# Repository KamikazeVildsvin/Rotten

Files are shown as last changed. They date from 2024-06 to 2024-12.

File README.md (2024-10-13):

# Rotten - DIY Pro Co RAT Clone
This repository contains the KiCad files for a DIY clone of the classic Pro Co RAT distortion effect pedal.
The schematic is an implementation of the one found on [ElectroSmash](https://www.electrosmash.com/proco-rat), so a big shout-out to them.
The article on [ElectroSmash](https://www.electrosmash.com/proco-rat) has a great description of the functionality of the circuit.

## Interactive BOM
An [interactive HTML BOM](https://html-preview.github.io/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) can be found in the `PCB/Rotten/bom` directory.
This can be used as a tool to easier populate the PCB.

## Images
### Schematic
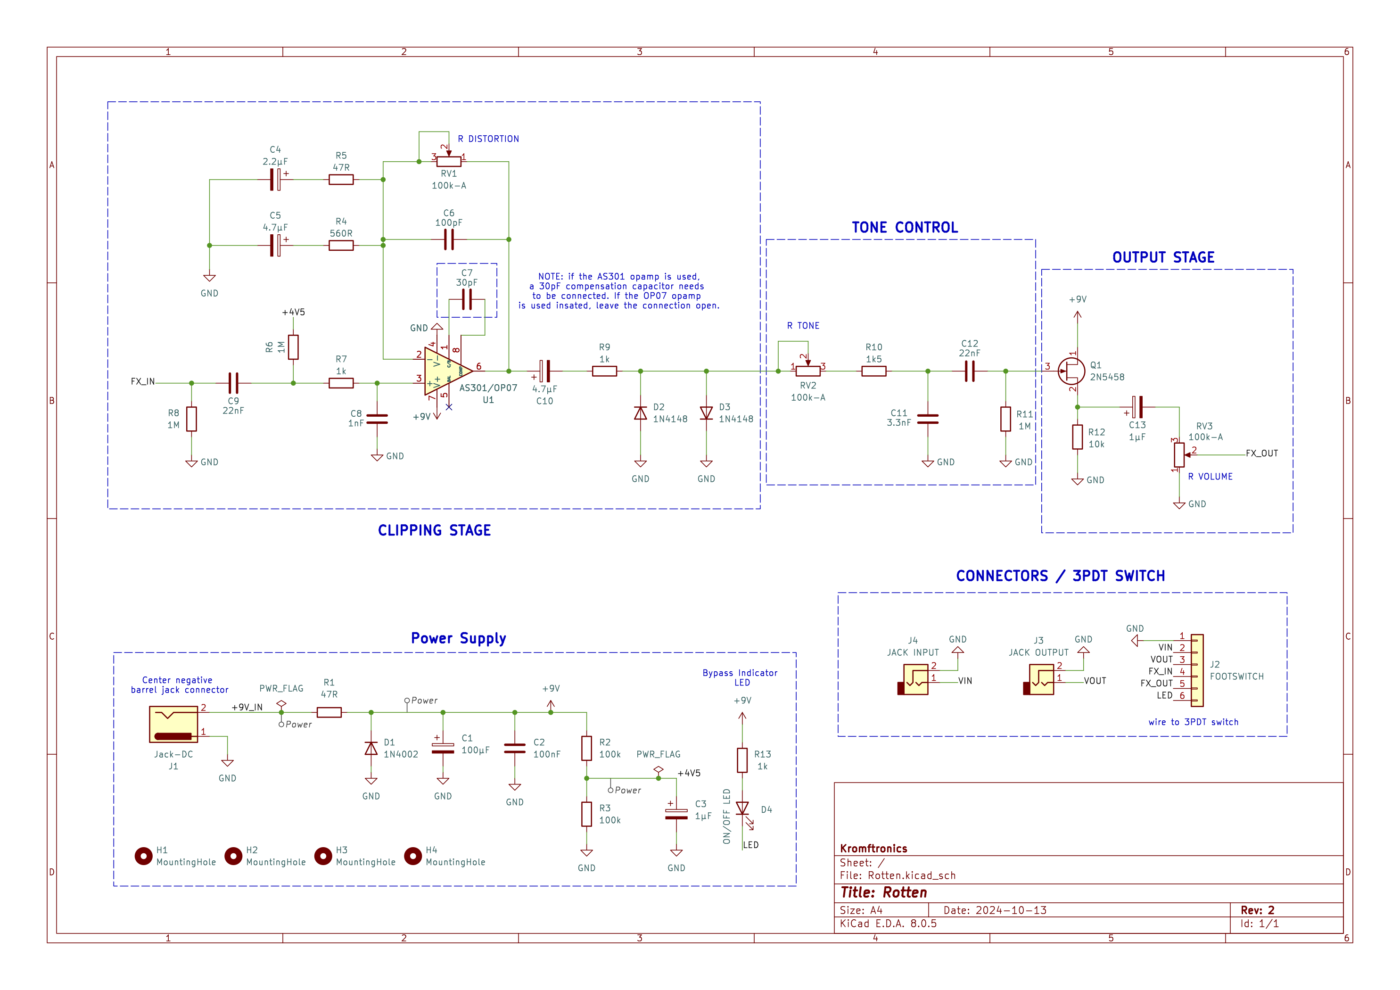
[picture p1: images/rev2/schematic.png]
Schematic Image

### PCB
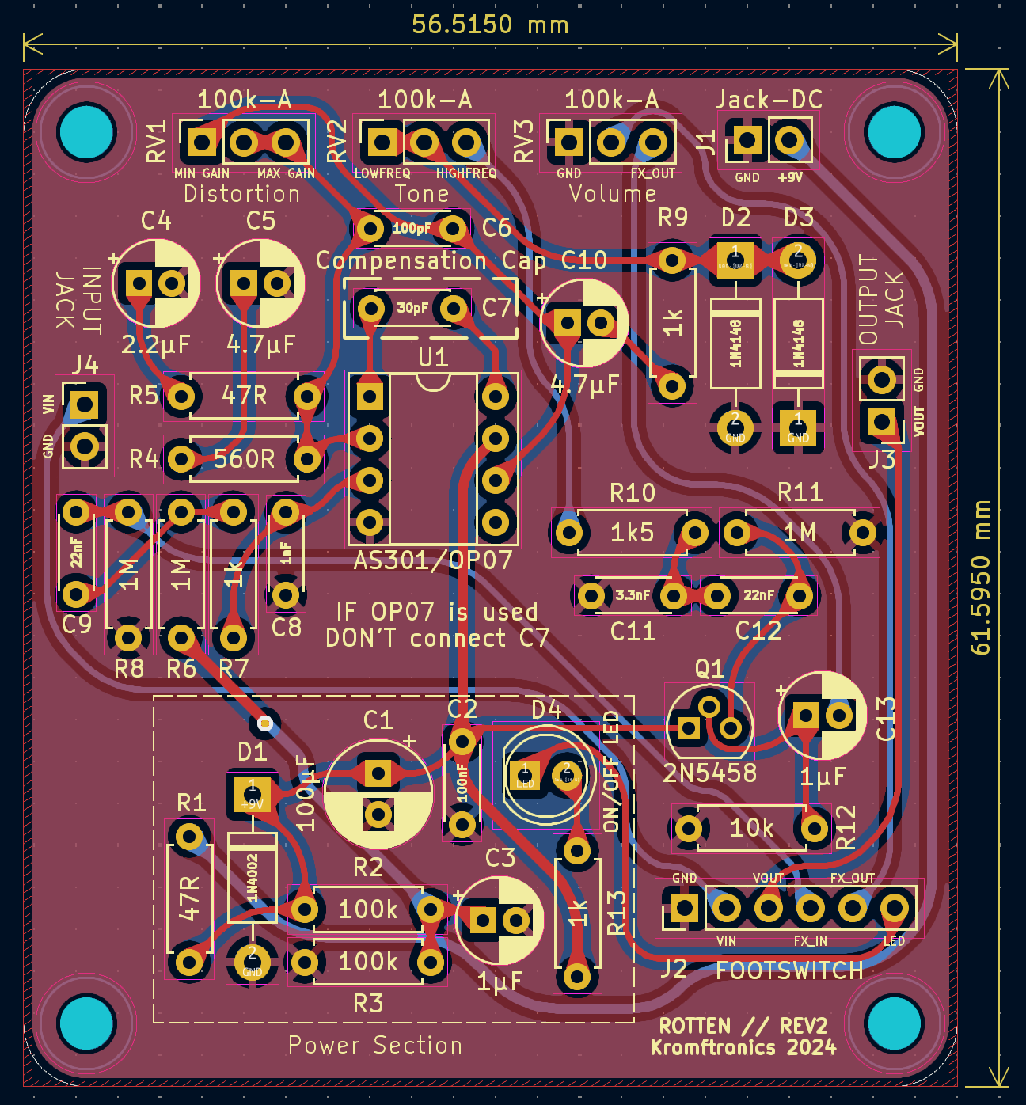
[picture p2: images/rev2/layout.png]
PCB Image

### 3D Model
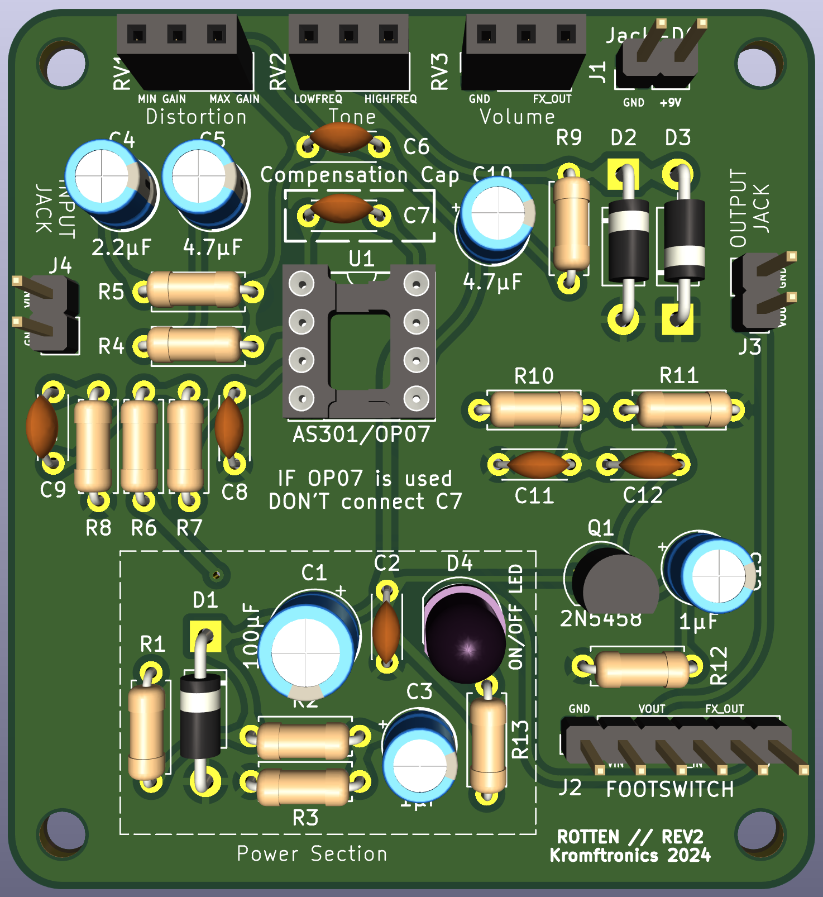
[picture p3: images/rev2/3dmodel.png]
PCB 3D Model

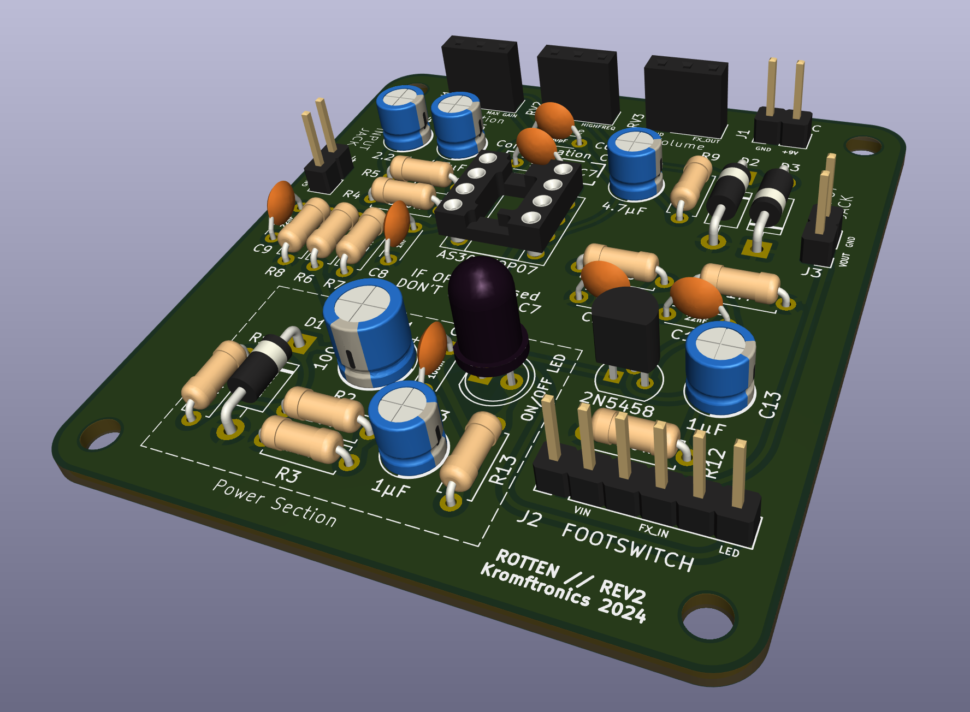
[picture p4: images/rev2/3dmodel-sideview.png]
PCB 3D Model Sideview


# Wiring
## Footswitch - True Bypass Wiring
You will need a 3PDT type switch in order to wire things correctly. 
The six connections on the PCB needs to be wired to the switch as indicated by the image below.

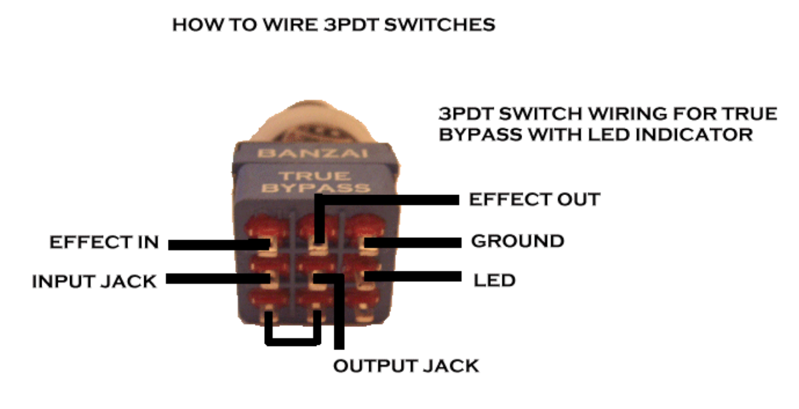
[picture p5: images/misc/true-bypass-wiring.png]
True Bypass Wiring

*source: https://support.banzaimusic.com/article/53-true-bypass-switch-wiring*

I would recommend that you use the interactive BOM above to see what connection on the PCB matches the correct pin on the footswitch, since the silkscreen is very small and probably not readable on the actual physical PCB.

*NOTE*: If you don't want to use the LED indicator, you can disregard the **GROUND** and **LED** connections on the footswitch and don't solder these connections to the PCB.

## Potentiometers
The PCB has been designed so pin 1, 2, and 3 on the board matches the pinout of the 100k Potentiometers.
This means that pin 1 on the potentiometer should go to the square pad on the PCB, as indicated below.

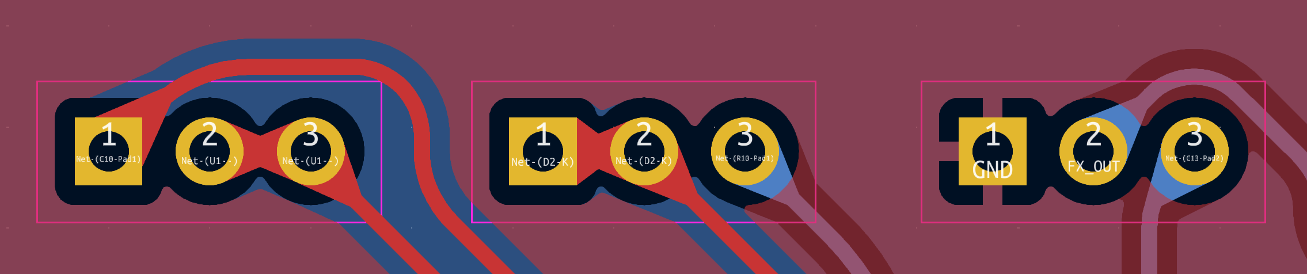
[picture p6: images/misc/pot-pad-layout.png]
Potentiometer Wiring


## Jack Connectors
The Jack connectors (both the 1/4" audio jacks and the DC jack) only needs two connections.
For the audio jacks, pin 1 should be soldered to the tib of the connector and the sleeve to pin 2.
The silkscreen on the PCB also indicates which pad is ground or the signal, as can be seen below

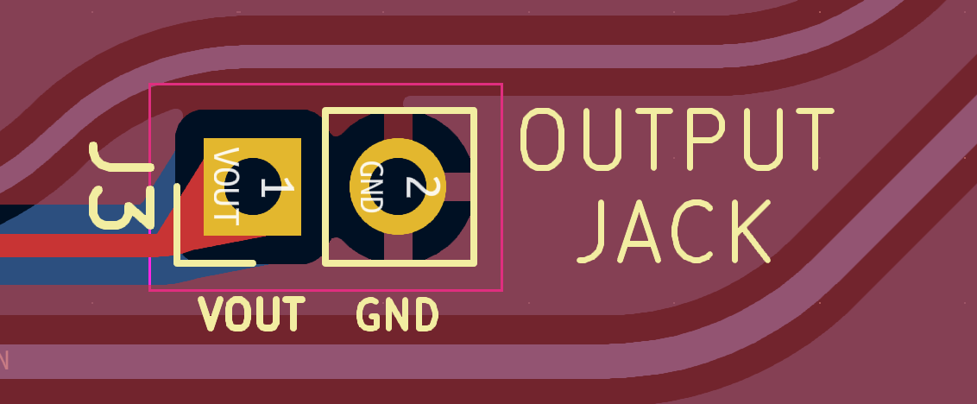
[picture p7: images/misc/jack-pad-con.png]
Audio Jack Wiring


The DC barrek jack needs to be connected center negatic in order for the effect to work with standard stompbox power supplies.
This means that you should connect the tip to ground and the **+9V** to the sleeve of the barrel jack connector.

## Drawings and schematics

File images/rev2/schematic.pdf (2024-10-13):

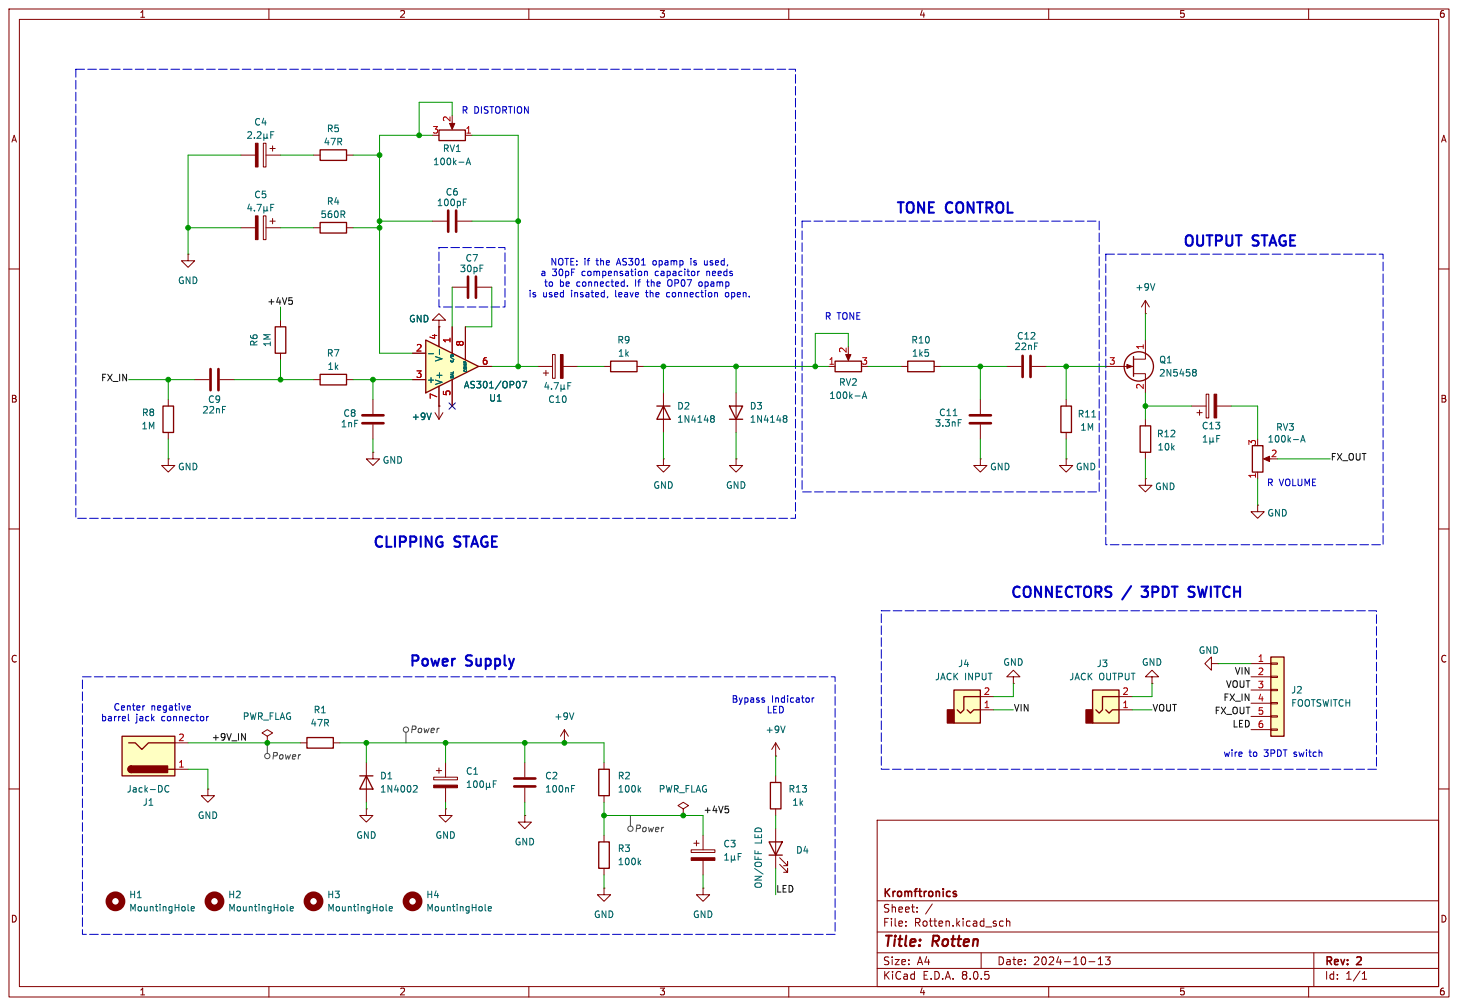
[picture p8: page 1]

wire to 3PDT switch OUTPUT STAGE

File: Rotten.kicad_sch Sheet: / Kromftronics

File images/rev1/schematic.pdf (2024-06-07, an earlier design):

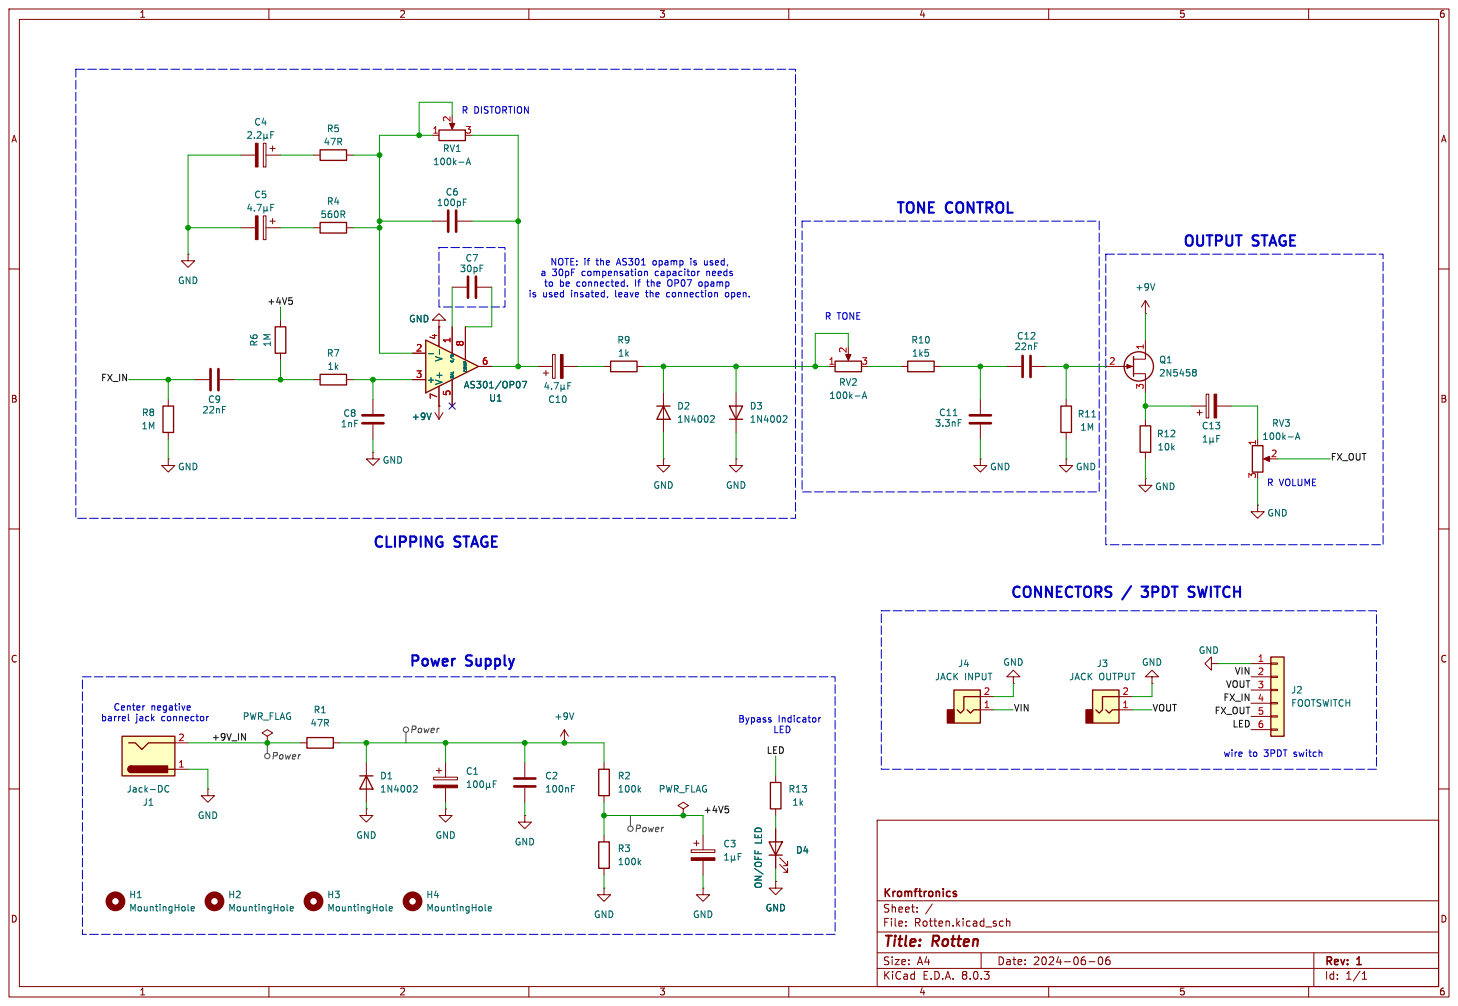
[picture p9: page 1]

Bypass Indicator LED CLIPPING STAGE

File: Rotten.kicad_sch Sheet: / Kromftronics

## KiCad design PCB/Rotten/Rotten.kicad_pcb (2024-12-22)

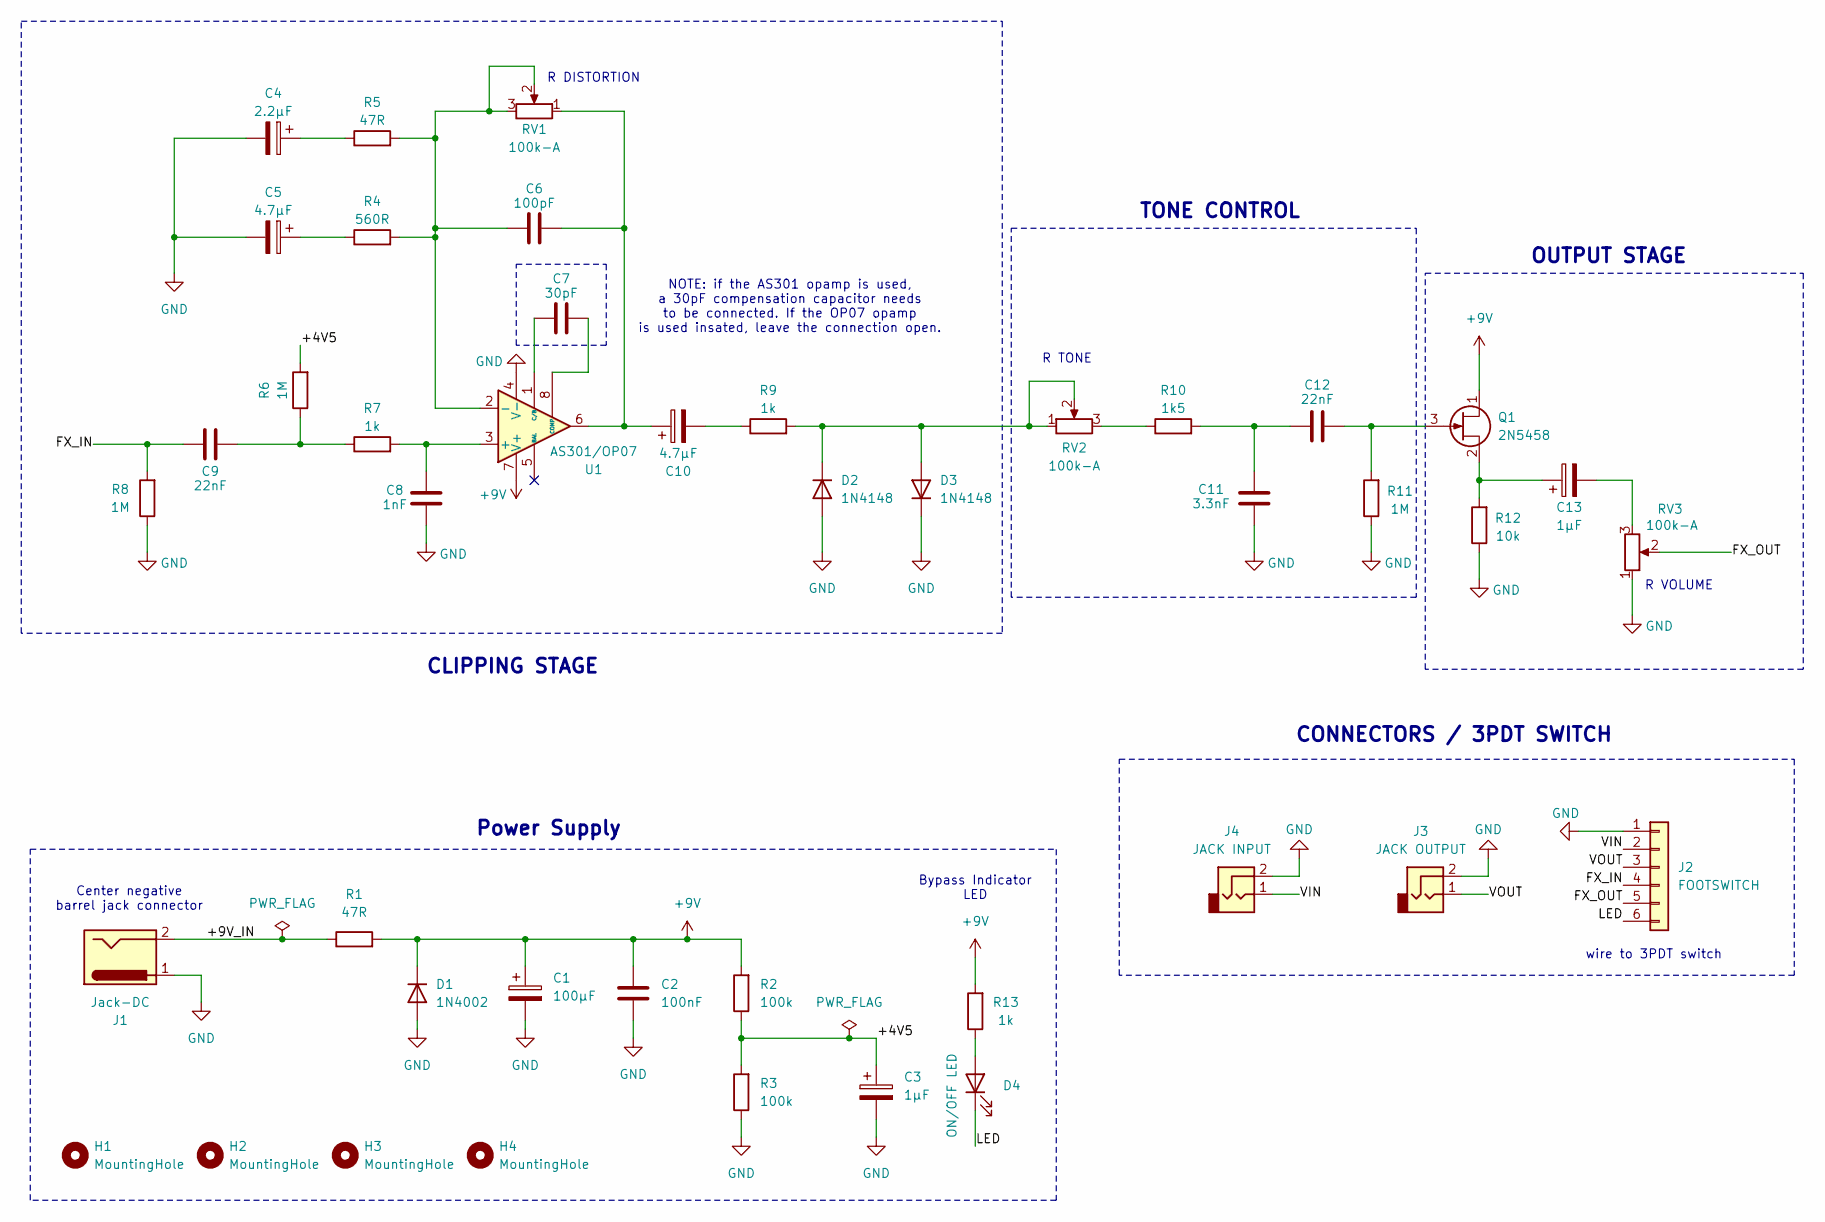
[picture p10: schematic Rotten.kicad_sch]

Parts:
C1: 100µF; CP_Radial_D6.3mm_P2.50mm
C2: 100nF; C_Disc_D4.3mm_W1.9mm_P5.00mm
C3, C13: 1µF; CP_Radial_D5.0mm_P2.00mm
C4: 2.2µF; CP_Radial_D5.0mm_P2.00mm
C5, C10: 4.7µF; CP_Radial_D5.0mm_P2.00mm
C6: 100pF; C_Disc_D4.3mm_W1.9mm_P5.00mm
C7: 30pF; C_Disc_D4.3mm_W1.9mm_P5.00mm
C8: 1nF; C_Disc_D4.3mm_W1.9mm_P5.00mm
C9, C12: 22nF; C_Disc_D4.3mm_W1.9mm_P5.00mm
C11: 3.3nF; C_Disc_D4.3mm_W1.9mm_P5.00mm
D1: 1N4002; D_DO-41_SOD81_P10.16mm_Horizontal
D2, D3: 1N4148; D_DO-41_SOD81_P10.16mm_Horizontal
D4: ON/OFF LED; LED_D5.0mm_IRBlack
H1, H2, H3, H4: MountingHole; MountingHole_3.2mm_M3_DIN965
J1: Jack-DC; PinHeader_1x02_P2.54mm_Vertical
J2: FOOTSWITCH; PinHeader_1x06_P2.54mm_Vertical
J3: JACK OUTPUT; PinHeader_1x02_P2.54mm_Vertical
J4: JACK INPUT; PinHeader_1x02_P2.54mm_Vertical
Q1: 2N5458; TO-92
R1, R5: 47R; R_Axial_DIN0207_L6.3mm_D2.5mm_P7.62mm_Horizontal
R2, R3: 100k; R_Axial_DIN0207_L6.3mm_D2.5mm_P7.62mm_Horizontal
R4: 560R; R_Axial_DIN0207_L6.3mm_D2.5mm_P7.62mm_Horizontal
R6, R8, R11: 1M; R_Axial_DIN0207_L6.3mm_D2.5mm_P7.62mm_Horizontal
R7, R9, R13: 1k; R_Axial_DIN0207_L6.3mm_D2.5mm_P7.62mm_Horizontal
R10: 1k5; R_Axial_DIN0207_L6.3mm_D2.5mm_P7.62mm_Horizontal
R12: 10k; R_Axial_DIN0207_L6.3mm_D2.5mm_P7.62mm_Horizontal
RV1, RV2, RV3: 100k-A; PinSocket_1x03_P2.54mm_Vertical
U1: AS301/OP07; DIP-8_W7.62mm_Socket

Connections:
+9V: C1.1, C2.1, D1.1 (K), Q1.1 (D), R1.2, R2.2, R13.2, U1.7 (V+)
/+4V5: C3.1, R2.1, R3.2, R6.2
/+9V_IN: J1.2, R1.1
/FX_IN: C9.1, J2.4, R8.2
/FX_OUT: J2.5, RV3.2
/LED: D4.1 (K), J2.6
/VIN: J2.2, J4.1
/VOUT: J2.3, J3.1
GND: C1.2, C2.2, C3.2, C4.2, C5.2, C8.2, C11.2, D1.2 (A), D2.2 (A), D3.1 (K), J1.1, J2.1, J3.2, J4.2, R3.1, R8.1, R11.1, R12.1, RV3.1, U1.4 (V-)
unnamed: C4.1, R5.1
unnamed: C5.1, R4.1
unnamed: C9.2, R6.1, R7.1
unnamed: C6.1, C10.1, RV1.1, U1.6
unnamed: C10.2, R9.1
unnamed: C11.1, C12.1, R10.2
unnamed: C13.2, RV3.3
unnamed: D2.1 (K), D3.2 (A), R9.2, RV2.1, RV2.2
unnamed: D4.2 (A), R13.1
unnamed: C12.2, Q1.3 (G), R11.2
unnamed: C13.1, Q1.2 (S), R12.2
unnamed: R10.1, RV2.3
unnamed: C8.1, R7.2, U1.3 (+)
unnamed: C6.2, R4.2, R5.2, RV1.2, RV1.3, U1.2 (-)
unnamed: C7.1, U1.8 (COMP)
unnamed: C7.2, U1.1 (C/B)

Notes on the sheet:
TONE CONTROL
Power Supply
R VOLUME
CLIPPING STAGE
wire to 3PDT switch
NOTE: if the AS301 opamp is used, a 30pF compensation capacitor needs to be connected. If the OP07 opamp is used insated, leave the connection open.
R DISTORTION
Bypass Indicator LED
OUTPUT STAGE
CONNECTORS / 3PDT SWITCH
Center negative barrel jack connector
R TONE

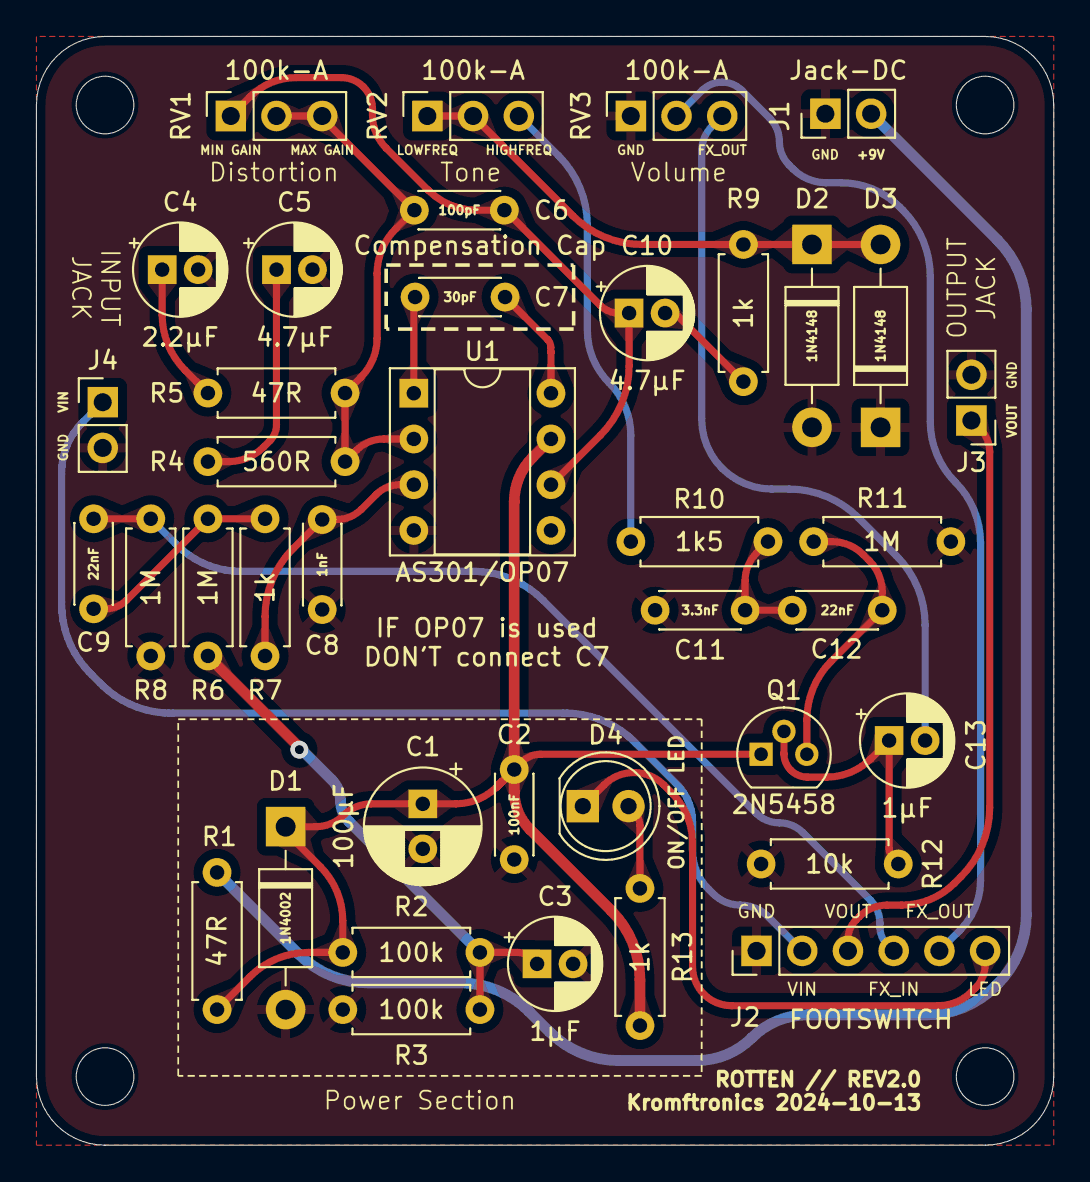
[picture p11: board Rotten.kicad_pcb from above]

Board: 2 copper layers, 56.5 x 61.6 mm, 43 parts (0 on the bottom side), 25 nets.

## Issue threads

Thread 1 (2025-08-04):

Does the current revision of the pcb work?

ccccc382, 2025-08-04:
Thanks for sharing the PCB files publicly! I just wanted to confirm the PCB files in their current version are working as expected? I'm planning to order a board and wanted to make sure there are no known issues before proceeding. Thanks!

KamikazeVildsvin, 2025-08-04:
Hi @ccccc382, thanks for the interest. Yes, the PCB files should be working. I only assembled a REV1 of the circuit, but the current REV2 should contain the "fixes" that I found. Hope that you'll finde the PCB useful. Cheers!

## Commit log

2024-06-05 created .gitignore. Created KiCad project
    [Rotten.kicad_pcb, Rotten.kicad_sch]
2024-06-05 created schematic. Imported footprints into PCBNew
    [Rotten.kicad_pcb, Rotten.kicad_sch]
2024-06-06 created rev1 layout and added images
    [Rotten.kicad_pcb, Rotten.kicad_sch]
2024-06-06 saved files
    [Rotten.kicad_pcb]
2024-06-07 added ElectroSmash citation to README. Added pdf of the schematic.
2024-06-07 renamed rev1 schematic pdf
2024-06-07 added png version of rev1 schematic
2024-06-07 Added schematic png to README
2024-06-08 changed clipping diodes to 1N4148. Updated schematic and PCB images. Generated an HTML BOM.
    [Rotten.kicad_pcb, Rotten.kicad_sch]
2024-06-08 Update README.md with link and description of the interactive BOM
2024-10-12 Added footswitch wiring image and description to README. Added note about wrong LED circuit.
2024-10-12 Updated README with better description of the footswitch wiring.
2024-10-13 Created Rev2 update! Fixed LED footswitch error that resulted in no light. Flipped "volume" and "gain" connections on PCB (1 -> 3). Fixed wrong pinout on JFET that resulted in no audio. Updated READM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
    [Rotten.kicad_pcb, Rotten.kicad_sch]
2024-12-22 Added variable revision and issue date on the silkscreen, so I don't forget to update the rev and issue date on the silkscreen.
    [Rotten.kicad_pcb]
